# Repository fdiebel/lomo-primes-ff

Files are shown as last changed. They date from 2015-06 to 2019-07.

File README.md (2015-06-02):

Follow Focus Gear - LOMO Prime Lens
=============

A follow focus gear for LOMO prime lenses designed to replace the original 0.5mm pitch gears with gears that are cinema standard 0.8mm.

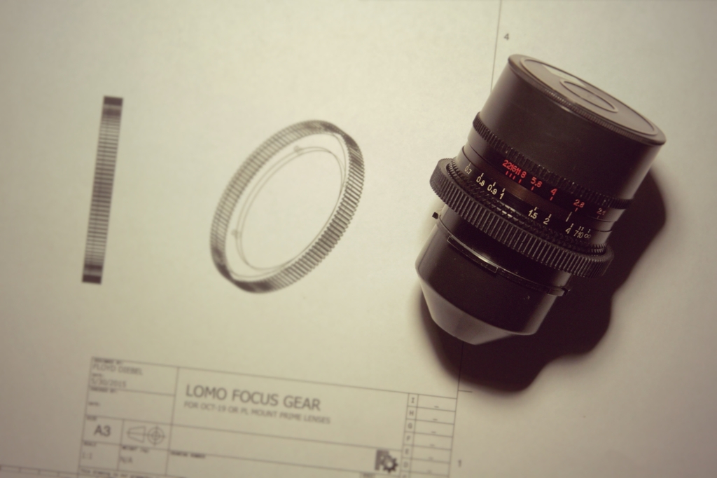
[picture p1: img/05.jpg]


I never liked the fact that the original LOMO gears have such a thin contact area, so this new design increases that to a full 10mm.

There are a few variations in the way these lenses are built, so I have included 3 screw and 4 screw versions of the design, as well as a version that has clearance for the bayonet mount. Using this design in theory should let you install the focus ring without having to remove the lens mount, assuming the original focus ring can be removed in the same way.

If removing your lens mount is required for installation and you are not comfortable doing so, take your lens to a professional for installation.

Designed with [FreeCAD](http://www.freecadweb.org/).

Instructions
--------
I printed with HIPS filament on the following settings, and results were great

* Layer height: 0.22
* Walls: 1.05
* Fill: 20

I suppose if you're concerned about the aesthetics you could use 0.1 layers but to my eye it really wasn't enough a difference to justify the print time.

Author
--------
Floyd Diebel (fdiebel)
* <http://emrl.com/>
* <https://www.facebook.com/advertisingisnotacrime> 

License
--------
Creative Commons - Attribution - Share Alike license.

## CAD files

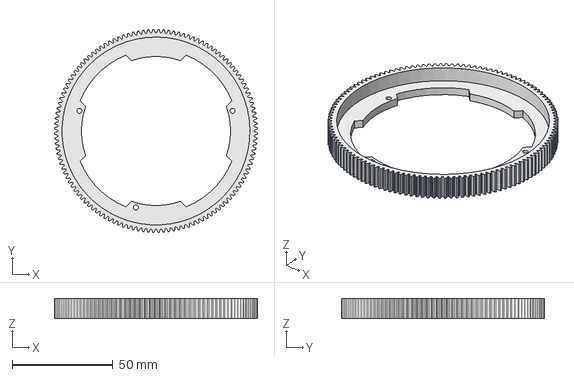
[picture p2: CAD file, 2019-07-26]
src/lomo-prime-ff_92mm-barrel_3pt-cutaway.FCStd
100.8 x 100.8 x 10.0 mm

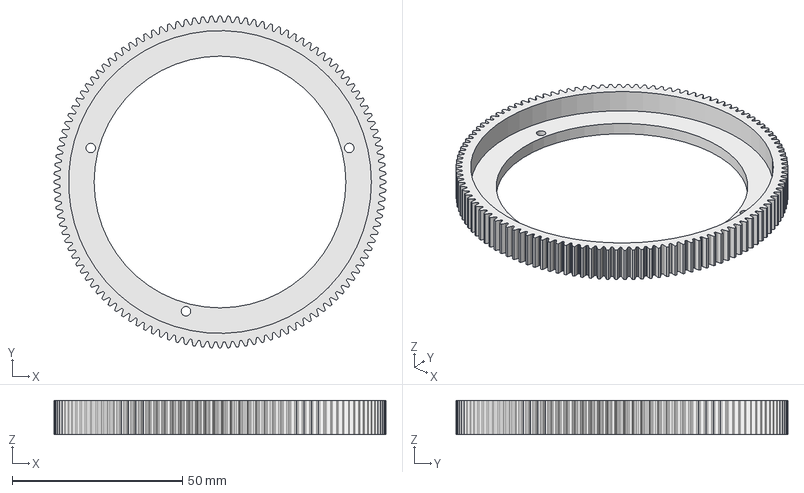
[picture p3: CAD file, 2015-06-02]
src/lomo-prime-ff-3pt.FCStd
97.6 x 97.6 x 10.0 mm

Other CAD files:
stl/lomo-prime-ff_92mm-barrel_3pt-cutaway.stl
stl/lomo-prime-ff-4pt.stl
src/lomo-prime-ff-3pt-cutaway.FCStd
stl/lomo-prime-ff-3pt-cutaway.stl
src/lomo-prime-ff-4pt.FCStd
stl/lomo-prime-ff-3pt.stl
src/lomo-prime-ff-blank.FCStd

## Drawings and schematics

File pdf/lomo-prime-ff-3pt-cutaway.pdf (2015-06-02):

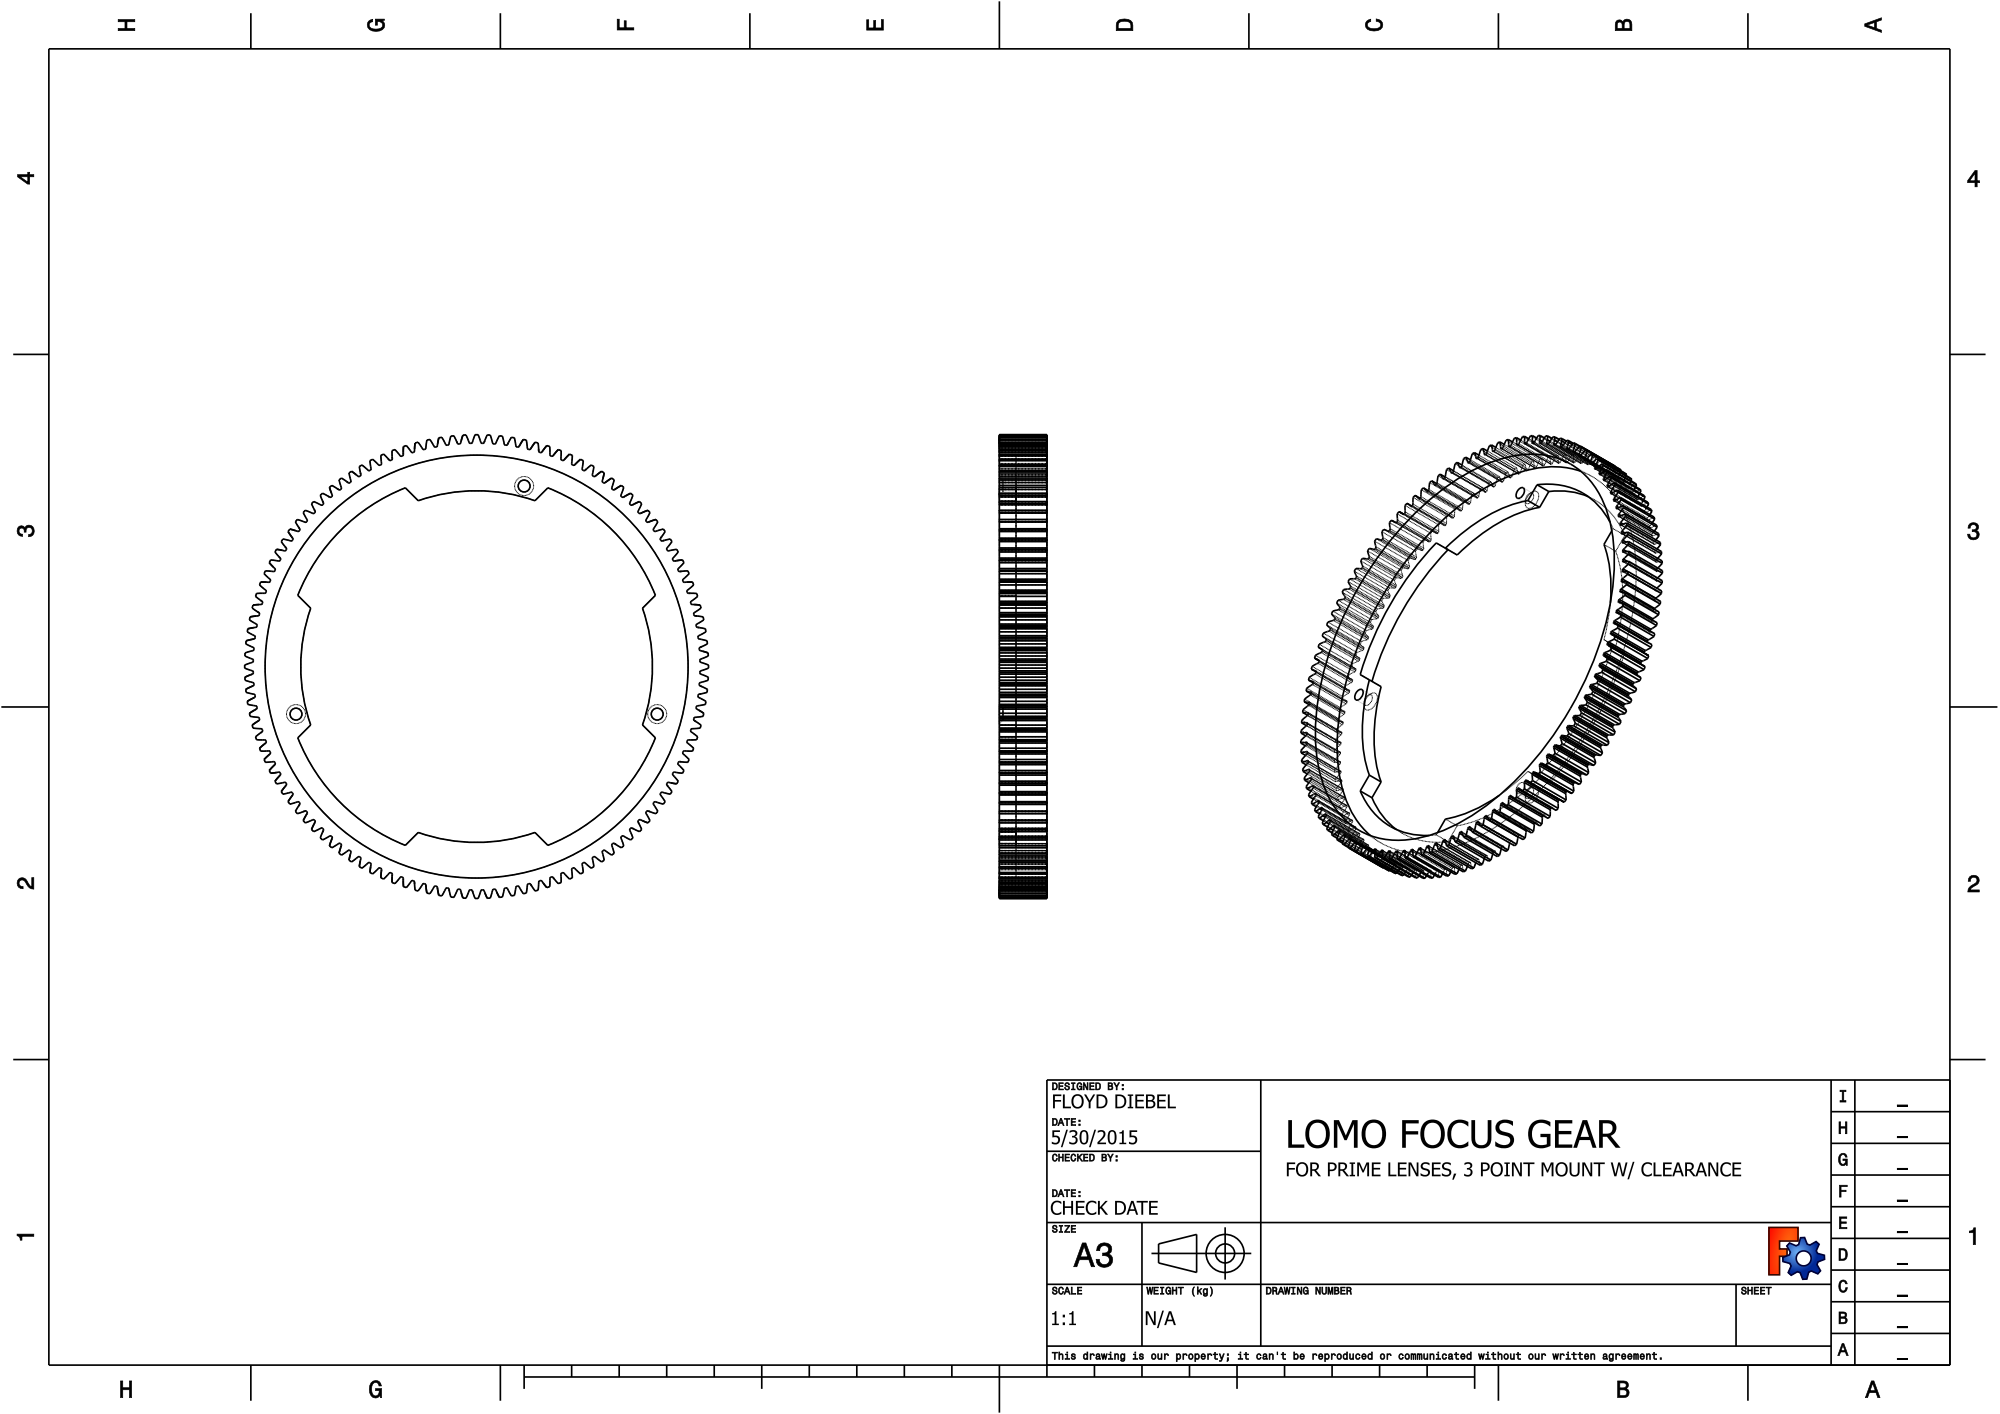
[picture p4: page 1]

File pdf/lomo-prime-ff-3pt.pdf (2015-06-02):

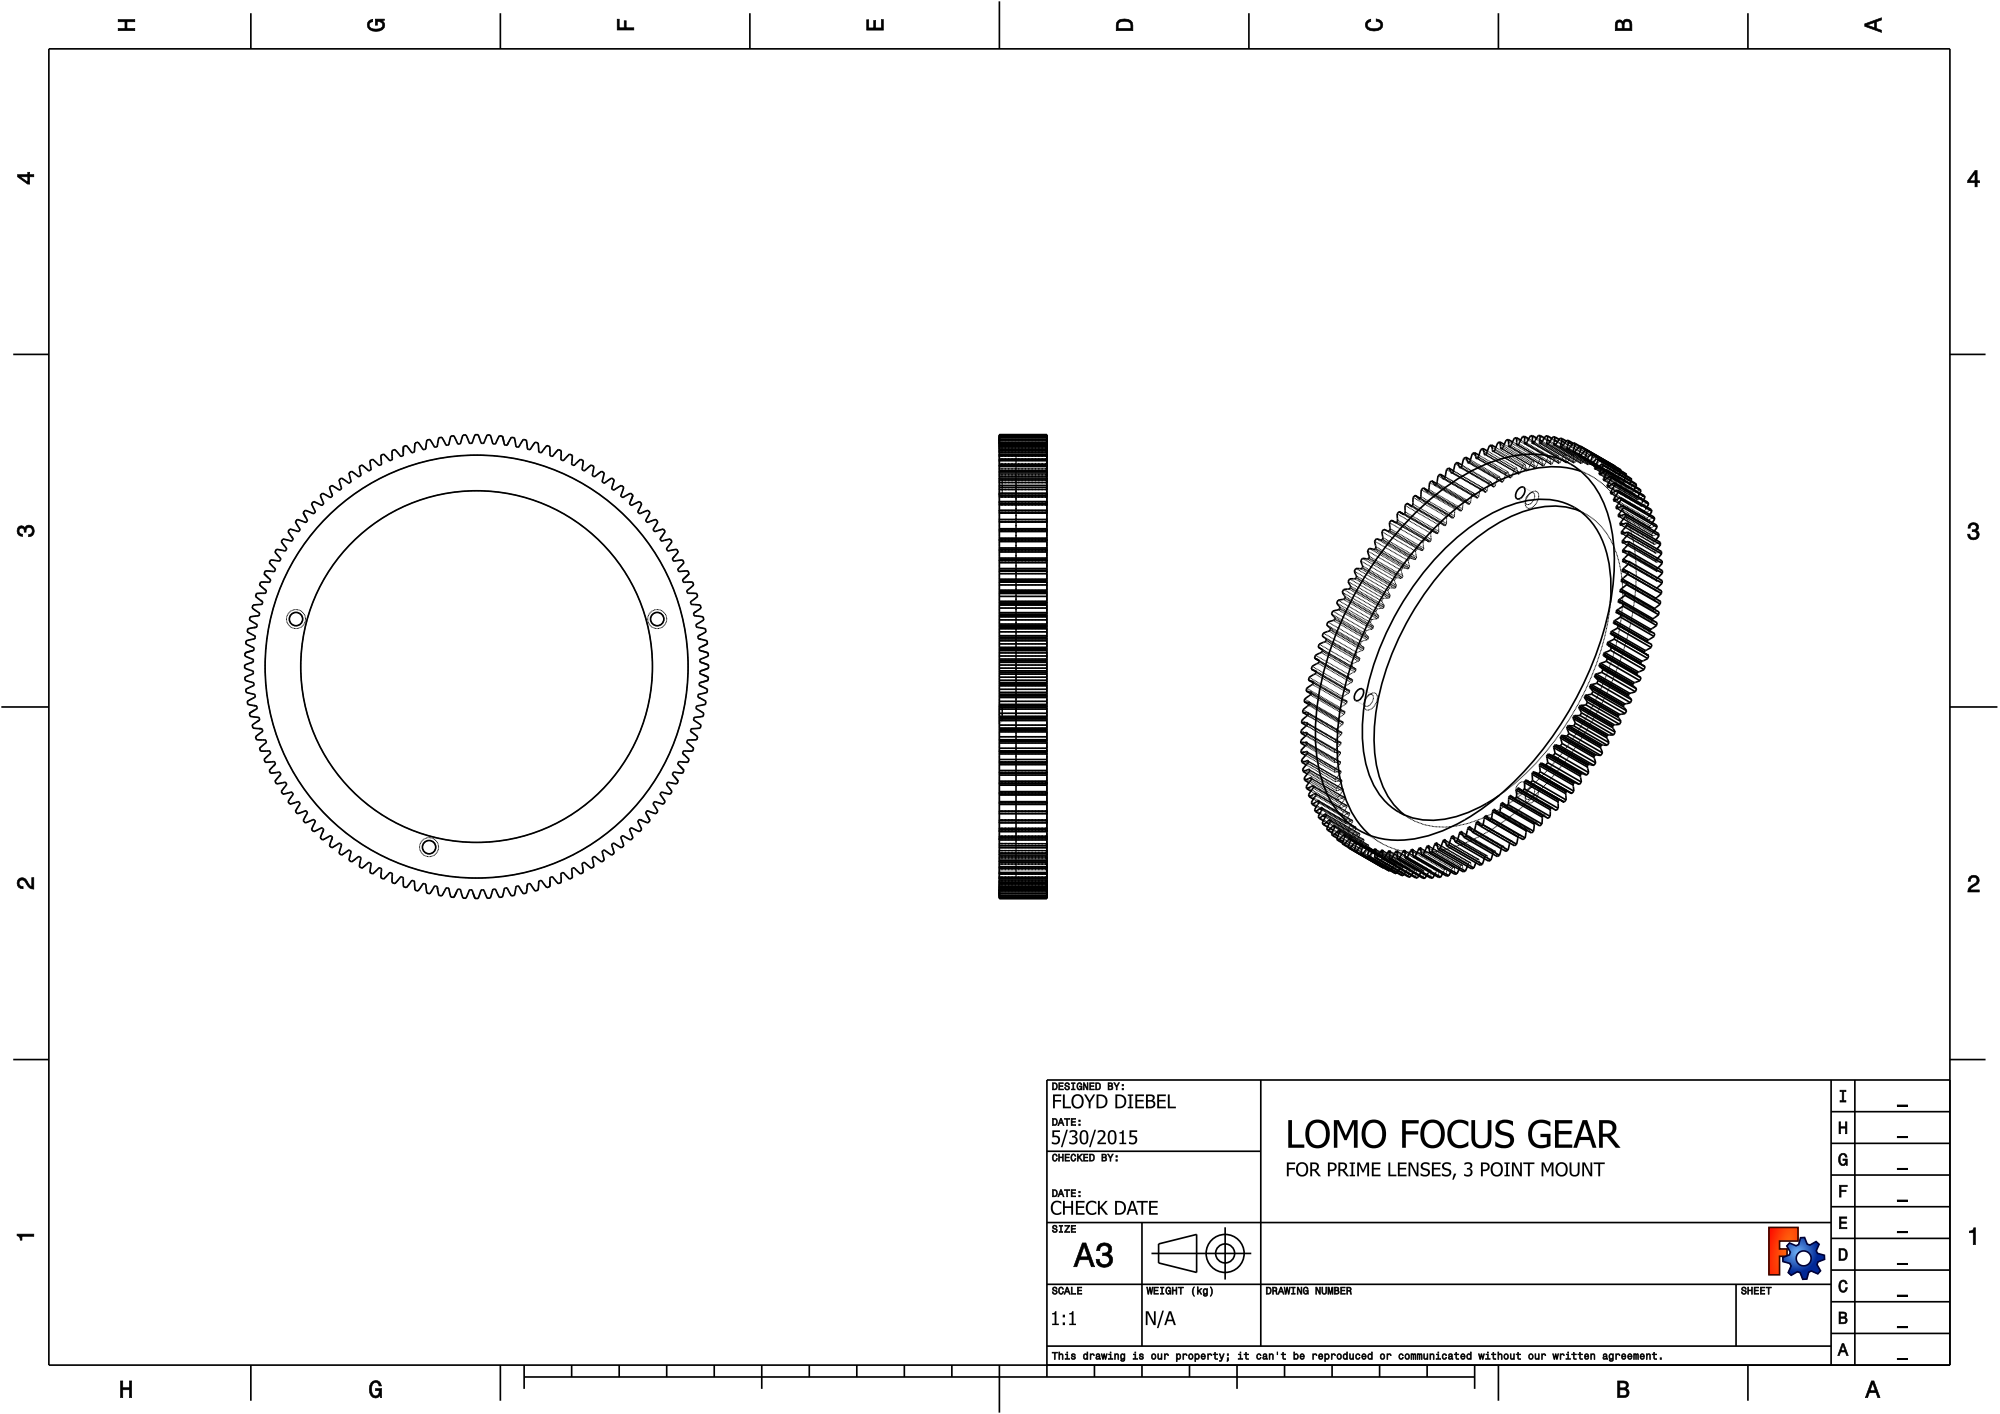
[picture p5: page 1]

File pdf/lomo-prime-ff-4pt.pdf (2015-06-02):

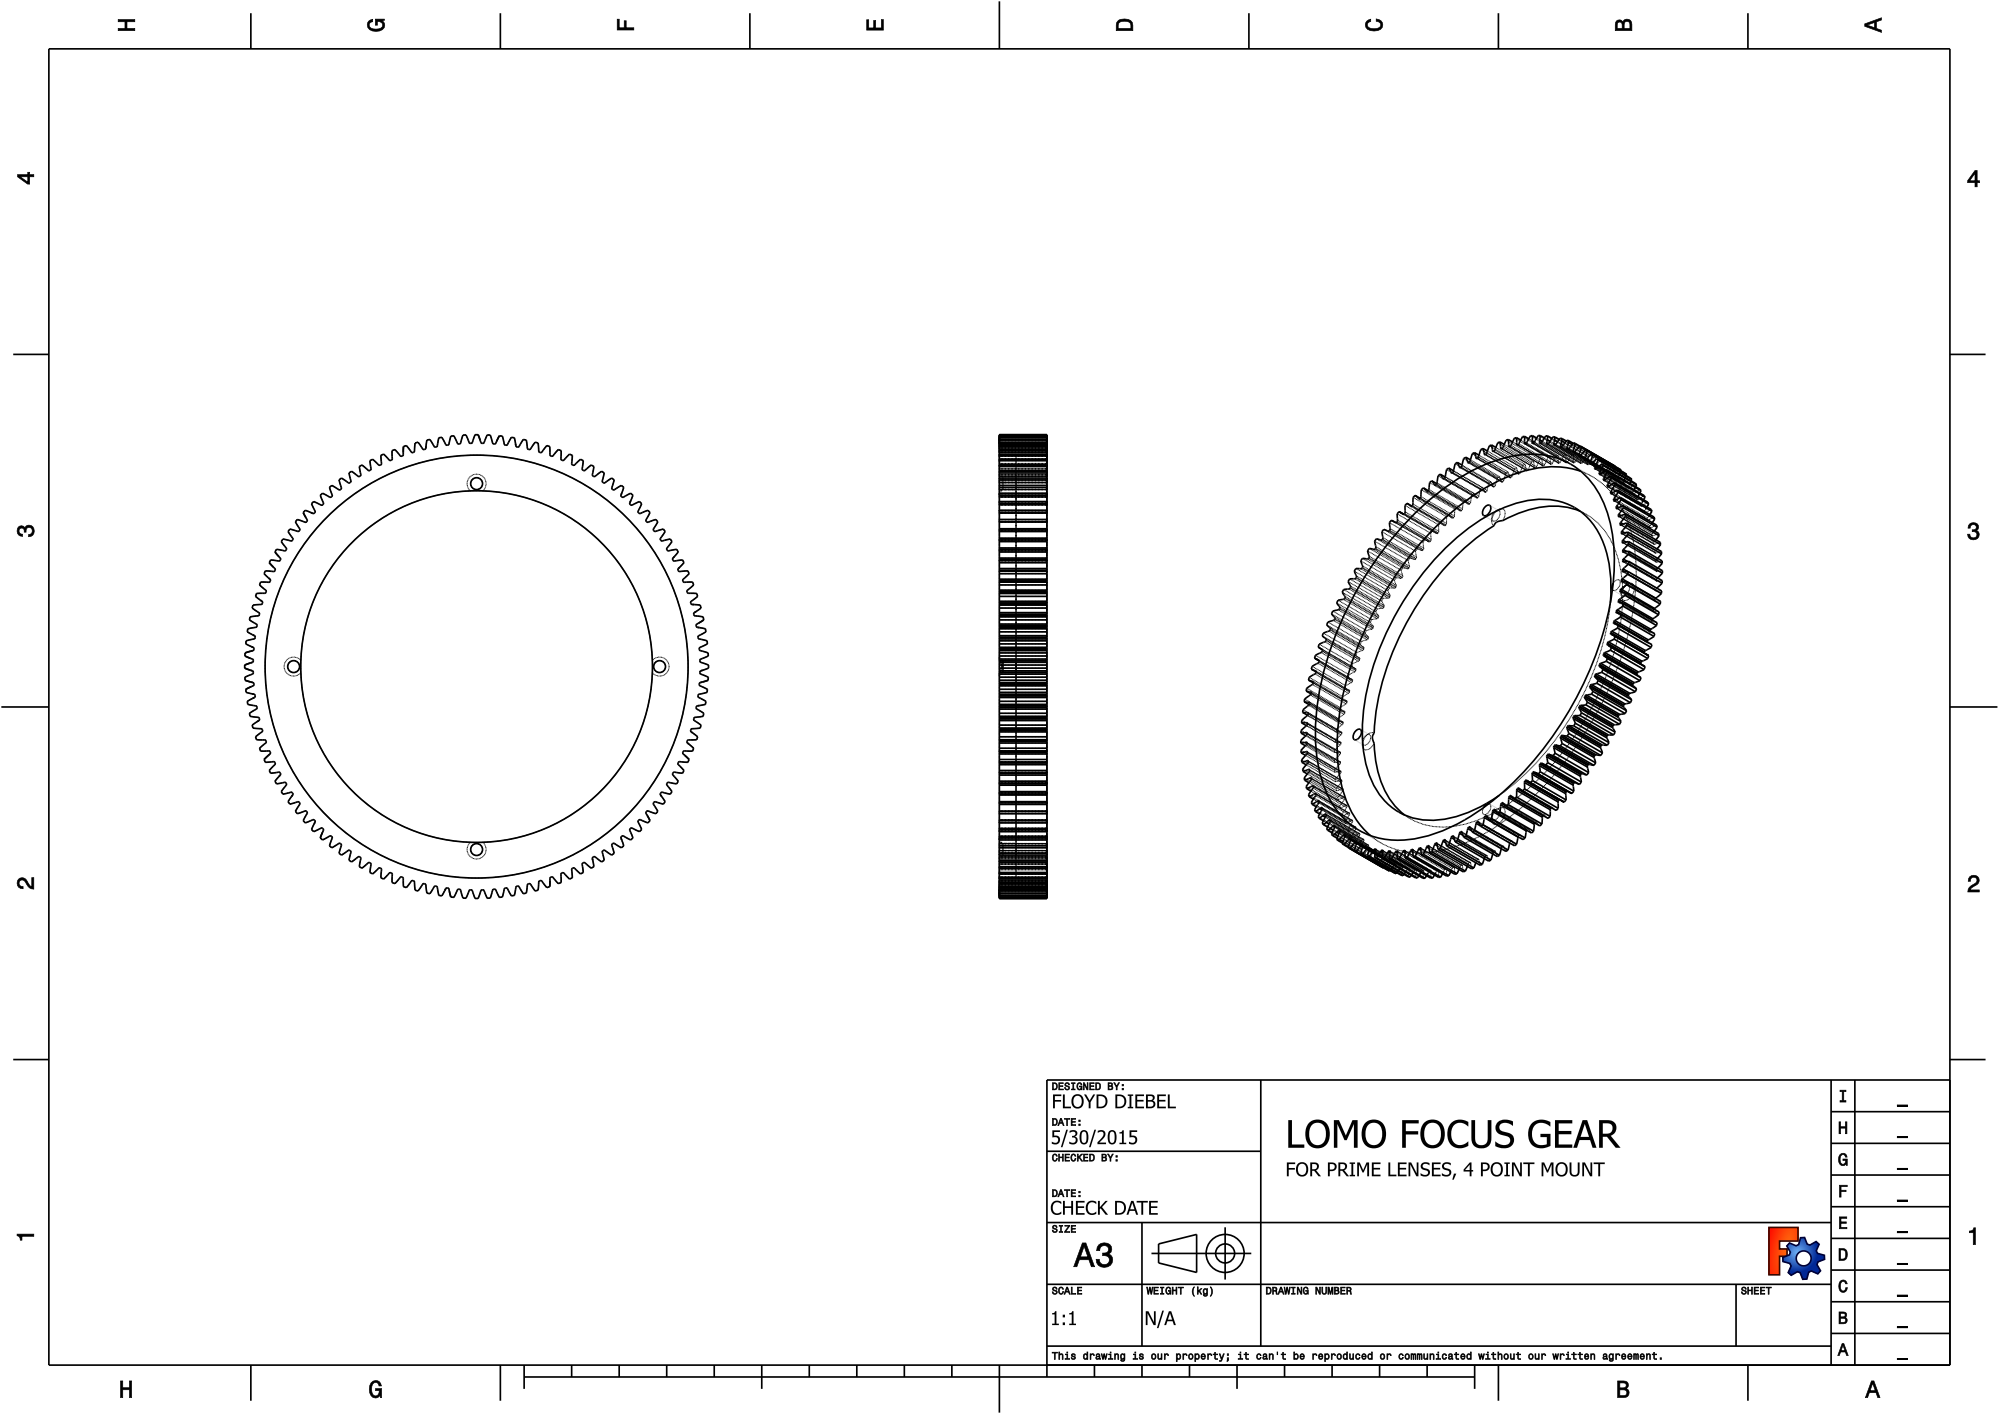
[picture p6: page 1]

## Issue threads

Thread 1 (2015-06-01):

Problem with later lenses

fdiebel, 2015-06-01:
Seems like later lenses have a little lip, and need an increased diameter for the barrel.

fdiebel, 2015-06-03:
Fixed.

Closed 2015-06-03.

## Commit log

2015-06-01 Setting up repository
    [lomo-prime-ff.FCStd, lomo-prime-ff.stl]
2015-06-01 Increased inside radius to 36.75mm
    [lomo-prime-ff.stl]
2015-06-01 Added 3 point mounting options
    [lomo-prime-ff-3pt-cutaway.FCStd, lomo-prime-ff-3pt-cutaway.stl, lomo-prime-ff-3pt.FCStd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]
2015-06-01 Cleaning up project
    [lomo-prime-ff-4pt.FCStd, lomo-prime-ff-4pt.stl, lomo-prime-ff.FCStd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]
2015-06-02 Small tweaks
    [lomo-prime-ff-3pt-cutaway.FCStd, lomo-prime-ff-3pt-cutaway.stl, lomo-prime-ff-3pt.FCStd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]
2019-07-26 Added 3 point version for 92mm lens barrel
    [lomo-prime-ff_92mm-barrel_3pt-cutaway.FCStd, lomo-prime-ff_92mm-barrel_3pt-cutaway.stl]
